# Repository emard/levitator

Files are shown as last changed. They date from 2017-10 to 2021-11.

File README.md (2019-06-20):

# Magnetic Levitation Toy

Object that horizonally levitates, artwork inspired
by flying a rocket to the Moon and back.

Magnets counter the gravity and provide forward
horizontal force (thrust) that is compensated
with a thread (rocket is anchored to the Moon).

3D printable parts, M3 threaded stainless steel rod
and 6 round (cylinder) neodymium magnets (0.5 T, grade N35).

    D =  6 mm, L = 10 mm, rod 14 mm
    D = 10 mm, L = 10 mm, rod 25 mm
    D = 12 mm, L = 12 mm, rod 25 mm

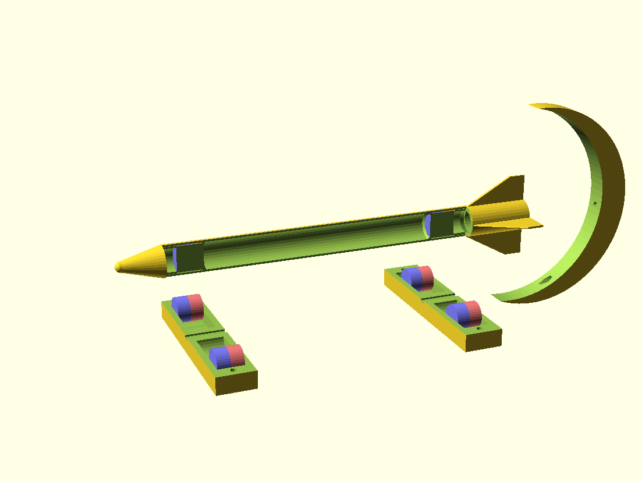
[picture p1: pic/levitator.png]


Range of mechanical stability is very narrow.
Millimeter precison adjustment is required to make
it right.

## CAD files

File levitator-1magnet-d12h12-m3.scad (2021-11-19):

include <levitator.scad>

/*
slicer-prusa

Print Settings:
layer height: 0.3 mm

Vertical sheels:
Perimeters: 2
Spiral vase: [ ]

Horizontal shells:
Solid layers: top: 2  bottom: 2

Infill: 10%

Output options:
Sequential individual objects [x]
Extruder clearance: Radius: 40 mm  Height: 40 mm

Advanced:
Seam: Nearest
[ ] External perimeters first

Printer Settings:
Extruder:
Retraction:
Length: 2.5 mm
Lift Z: 0.1 mm

Advanced
Use relative E distances: [ ]
Use firmware retraction:  [ ]
Use volumetric E:         [ ]
Enable variable layer
height feature:           [x]
*/

magnet_h=12;
magnet_d=12;

screw=3; // M3 screw
use_screws=0; // 0-disable screws, 1-enable screws
screw_plastic=2.2; // plastic hole dia
screw_plastic_tight=screw_plastic*0.82; // tight
// echo(screw_plastic_tight);
screw_plastic_loose=screw_plastic*1.1;
screw_plastic_head=screw_plastic*2.2;
screw_plastic_transition=1.5; // cone for easier printing
screw_plastic_under=3; // not counting transition

clr_magnet_d=0.5; // diameter clearance
clr_magnet_h=0.4; // length clearance
clr_screw_hole=0.25; // hole bit bigger
clr_screw_step=1; // screw spacing clearance

tube_wall=1.5; // wall thickness
tube_len=120; // tube length

screw_step=magnet_h+screw+clr_screw_step;
// screw_step=2*screw;

cylinder_faces=32; // smoothness

holder_depth=15;
// holder_width=72; // should be calculated from magnet_last and screw size
holder_height=15;
holder_thinner=0.35; // factor that makes middle bar thinner
holder_clr_magnet_d=clr_magnet_d;
holder_clr_magnet_h=clr_magnet_h;
magnet_first=[23,22]; // head,tail (22-23)
magnet_last=magnet_first; // head,tail
magnet_n=[1,1]; // tail,head
// magnet_step=5; // obsolete
magnet_height=holder_height/2;
holder_clearance=use_screws > 0.5 ? 0.3 : 0;

// stand

stand_d=10; // at threaded rod
stand_length=70;
stand_width=8;
stand_thickness=5;
stand_foot_length=70;
stand_foot_d=stand_width; // at floor

// head

head_len=18;
inlet_h=5;
head_inlet_clr=0.14; // head inlet clearance
head_transition=0.5; // easier printing
tiph=-2; // from tip to cutoff inside cone
head_tip=4; // tip diameter
head_tube_len=0; // head extension (like body)

// tail

tail_inlet_clr=0.13; // inlet clearance
wings=4;
wing_h1=10; // straignt height of the wing
wing_h2=40; // total wing height
wing_width=10;
wing_thick=tube_wall/2; // thickness
tail_transition=2;
holder_bar_h=4;

// stopper
stop_d=magnet_d-2*clr_magnet_d; // small d
stop_h=1.5;

levitation_h=37;

// moon artwork
moon_d1=levitation_h*2;
moon_d2=levitation_h*2;
moon_crescent=10;
moon_thick=8;
moon_angle=9;
moon_clr_screw_hole=0.2; // must be tight enough

// Rocket (spiral vase)
if(0)
  head();
if(0)
  tail();
if(0)
  rocket_tube();
// Stator (normal slicing)
if(0)
  printable_holders();
if(0)
  stand();
if(0)
  moon();

// cross section
if(1)
    // translate([0,0,55])
difference()
{
    // magnet_holder();
    // head();
    // tail();
    full_assembly(magnets=1);
    if(1)
    translate([magnet_d,0,0])
    cube([magnet_d*2,tube_len,magnet_d*2],center=true);
}

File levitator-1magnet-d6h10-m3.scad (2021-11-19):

include <levitator.scad>

/*
slicer-prusa

Print Settings:
layer height: 0.3 mm

Vertical sheels:
Perimeters: 1
Spiral vase: [ ]

Horizontal shells:
Solid layers: top: 1  bottom: 1

Infill: 10%

Output options:
Sequential individual objects [x]
Extruder clearance: Radius: 40 mm  Height: 40 mm

Advanced:
Seam: Nearest
[ ] External perimeters first

Printer Settings:
Extruder:
Retraction:
Length: 2.5 mm
Lift Z: 0.1 mm

Advanced
Use relative E distances: [ ]
Use firmware retraction:  [ ]
Use volumetric E:         [ ]
Enable variable layer
height feature:           [x]
*/

magnet_h=10;
magnet_d=6;

screw=3; // M3 screw
use_screws=0; // in plastic holders
screw_plastic=2.2; // plastic hole dia
screw_plastic_tight=screw_plastic*0.82; // tight
// echo(screw_plastic_tight);
screw_plastic_loose=screw_plastic*1.1;
screw_plastic_head=screw_plastic*2.2;
screw_plastic_transition=1.5; // cone for easier printing
screw_plastic_under=3; // not counting transition

clr_magnet_d=0.3; // diameter clearance (except holder)
clr_magnet_h=0.5; // length clearance (except holder)
clr_screw_hole=0.4; // hole bit bigger (except moon clr, defined on other place)
clr_screw_step=1; // screw spacing clearance

tube_wall=1.5; // wall thickness
tube_len=73; // tube length


screw_step=magnet_h+screw+clr_screw_step;

// screw_step=2*screw;

cylinder_faces=32;

holder_depth=15;
// holder_width=60; // obsolete, calculated from magnet_last and screw size
holder_height=8;
holder_thinner=0.5; // factor to make holder bars thinner
holder_clr_magnet_d=clr_magnet_d+0.2;
holder_clr_magnet_h=clr_magnet_h;
magnet_first=[14,13]; // head,tail
magnet_last=magnet_first;
magnet_n=[1,1]; // head,tail
magnet_height=holder_height/2; // in the middle of the holder
holder_clearance=use_screws > 0.5 ? 0.3 : 0;

// stand
stand_d=7; // at threaded rod
stand_length=50;
stand_width=6;
stand_thickness=5;
stand_foot_length=50;
stand_foot_d=6; // at floor

// head
head_len=12;
inlet_h=4;
head_inlet_clr=0.20; // head inlet clearance (positve=loose, negative=tight)
head_transition=0.5; // easier printing
tiph=-2; // from tip to cutoff inside cone
head_tip=3; // tip diameter
head_tube_len=0; // head extension (like body)

// tail
tail_inlet_clr=0.15; // tail inlet clearance (positive=loose, negative=tight)
wings=4;
wing_h1=5; // straignt height of the wing
wing_h2=25; // total wing height
wing_width=6;
wing_thick=tube_wall/2; // thickness
tail_transition=2;
holder_bar_h=4;

// stopper
stop_d=magnet_d-2*clr_magnet_d; // small d
stop_h=1.5;

levitation_h=21;

// moon artwork
moon_d1=2*levitation_h;
moon_d2=moon_d1;
moon_crescent=5; // width of crescent moon
moon_thick=7; // extrusion thickness
moon_angle=12;
moon_clr_screw_hole=0.15; // more tight, moon should not move

// ROCKET
if(0) // spiral vase seam rear
  head();
if(0) // spiral vase seam rear
  tail();
if(0) // spiral vase seam rear
  rocket_tube();
// STATOR
if(0) // print with seam: random for each piece be equal (no seam)
  printable_holders();
if(0)
  stand();
if(0)
  moon();

// cross section
if(1)
    // translate([0,0,55])
difference()
{
    // magnet_holder();
    // head();
    // tail();
    full_assembly(magnets=1);
    if(1)
    translate([magnet_d,0,0])
    cube([magnet_d*2,tube_len,magnet_d*2],center=true);
}

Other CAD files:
levitator-d10h10-m3.scad
levitator-d12h12-m3.scad
levitator-d6h10-m3.scad
levitator-insert-d6h10-m3.scad
levitator.scad
levitator/levitator.scad

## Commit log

2017-09-19 initial parts, 3D printable parts for the levitator
    [levitator.scad]
2017-09-20 closed magnet holder wip
    [levitator.scad]
2017-09-20 plastic screw head on the side
    [levitator.scad]
2017-09-20 magnet holder works. When 2 magnets are placed at most distant position, stable lifting field appears
    [levitator.scad]
2017-09-20 deleting out-of-directory file
    [levitator.scad]
2017-09-20 moving files around
    [levitator.scad]
2017-09-20 enable both halves
    [levitator.scad]
2017-09-22 levitator head done, fits tight into tube
    [levitator.scad]
2017-09-22 tail WIP
    [levitator.scad]
2017-09-22 tail inlet
    [levitator.scad]
2017-09-22 levitator - full assembly
    [levitator.scad]
2017-09-22 full assembly with holders
    [levitator.scad]
2017-09-23 dimensions adjusted
    [levitator.scad]
2017-09-23 full view
    [levitator.scad]
2017-09-23 moon angle changed
    [levitator.scad]
2017-09-23 proper orientation (rocket horizontal)
    [levitator.scad]
2017-09-23 reduce clearances on M3 rod and tail - more tight
    [levitator.scad]
2017-09-26 magnets shown in proper positions
    [levitator.scad]
2017-09-29 wing enclosing cone calculated
    [levitator.scad]
2017-09-29 various number of wings now works 3-n
    [levitator.scad]
2017-09-29 make it work for 2 wings also
    [levitator.scad]
2017-09-30 magnet_holder: set default argument magnet=0
    [levitator.scad]
2017-10-22 Separating library from geometry and making versions for magneds D=6 H=10 and D=10 H=10 mm
    [levitator-d10h10-m3.scad, levitator-d6h10-m3.scad, levitator.scad]
2017-10-24 cosmetics and D=6 dimensions adjustment, tightening head/tail inlet clearances
    [levitator-d10h10-m3.scad, levitator-d6h10-m3.scad, levitator.scad]
2017-10-24 dimensions adjustment
    [levitator-d6h10-m3.scad]
2017-10-25 smaller holders
    [levitator-d6h10-m3.scad]
2017-10-25 thinner moon
    [levitator-d6h10-m3.scad]
2017-10-25 update levitation height
    [levitator-d6h10-m3.scad]
2017-10-27 more configurable positions of magnets in the holders
    [levitator-d10h10-m3.scad, levitator-d6h10-m3.scad, levitator.scad]
2017-10-27 it works, maybe rocket is too steep upwards
    [levitator-d6h10-m3.scad]
2017-10-28 D=6 L=10 mm: adjusting dimensions so that rocket levitates mostly horizontal, with a slight up-slope. Thickening moon.
    [levitator-d6h10-m3.scad]
2017-10-28 D=6 L=10 larger tail (cosmetics)
    [levitator-d6h10-m3.scad]
2017-10-28 shorten tube 7->6cm, cosmetics
    [levitator-d6h10-m3.scad]
2017-10-28 simplifying design: holders without screws
    [levitator-d10h10-m3.scad, levitator-d6h10-m3.scad, levitator.scad]
2017-10-28 no screws, no holder clearance
    [levitator-d10h10-m3.scad, levitator-d6h10-m3.scad]
2017-10-28 D=10 L=10: tail holder is shorter than head holder
    [levitator-d10h10-m3.scad]
2017-10-28 no screws case: holder middle half-height, material and print time saving
    [levitator.scad]
2017-10-29 holder inner round a bit smaller than outer rounds. print time saving
    [levitator.scad]
2017-11-11 allow holder bar be optinally thinner by a factor
    [levitator.scad]
2017-11-11 update dimensions for 6x10, 10x10 and new 12x12 magnets
    [levitator-d10h10-m3.scad, levitator-d12h12-m3.scad]
2018-07-03 d6m10: more tight head and tail inlets
    [levitator-d6h10-m3.scad]
2018-07-03 d12h12: dimensions adjusted
    [levitator-d12h12-m3.scad]
2018-08-18 printing rocket and holders as one piece, pausing printer to insert magnets
    [levitator.scad]
2018-08-18 d=6 h=10 paused print for magnets insertion
    [levitator-insert-d6h10-m3.scad]
2018-08-18 floor stand
    [levitator.scad]
2018-08-18 d=6 h=10 with floor stand
    [levitator-insert-d6h10-m3.scad]
2018-08-19 pause example
    [levitator-insert-d6h10-m3.scad]
2018-08-19 d=12 h=12 updated geometry
    [levitator-d12h12-m3.scad]
2018-08-19 pause better explained
    [levitator-insert-d6h10-m3.scad]
2018-08-24 adjusting dimensions for magnet insertion
    [levitator-insert-d6h10-m3.scad]
2018-08-24 adjusting dimensions
    [levitator-d6h10-m3.scad]
2019-06-11 d6h10 update for standing at angle
    [levitator-d6h10-m3.scad]
2019-06-11 d6h10 reduce height
    [levitator-d6h10-m3.scad]
2019-06-11 d6h10: adjusting dimensions
    [levitator-d6h10-m3.scad]
2019-06-12 d12h12: adujusting dimensions
    [levitator-d12h12-m3.scad]
2019-06-17 moon screw hole clearance set separately to make it tight enough
    [levitator-d10h10-m3.scad, levitator-d12h12-m3.scad, levitator-d6h10-m3.scad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]
2019-06-17 d12h12: shorten tube 120->100 mm in order to move center of mass down. When using 250 mm threaded rod 120 mm tube was not stable if mounted at angle on a stand.
    [levitator-d12h12-m3.scad]
2019-06-18 trying to use "Seam: Nearest" (but seam looks the same)
    [levitator-d6h10-m3.scad]
2019-06-20 correctly placed magnets on full_assembly
    [levitator.scad]
2019-06-20 d12h12: tighten inlet clearance
    [levitator-d12h12-m3.scad, levitator-d6h10-m3.scad]
2019-06-20 top and bottom layers: same number of shells
    [levitator-d12h12-m3.scad, levitator-d6h10-m3.scad]
2020-12-15 head tube len parameter
    [levitator-d10h10-m3.scad, levitator-d12h12-m3.scad, levitator-d6h10-m3.scad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]
2020-12-26 support 1 and 2 magnets
    [levitator.scad]
2020-12-26 1-magnet update
    [levitator-1magnet-d6h10-m3.scad]
2020-12-26 increase clearances in magnet holder for mangets and rod
    [levitator-1magnet-d6h10-m3.scad]
2020-12-27 separate magnet clearance from holder
    [levitator.scad]
2020-12-27 followup common change in levitator.scad for separate magnet clr in holder
    [levitator-1magnet-d6h10-m3.scad, levitator-d10h10-m3.scad, levitator-d12h12-m3.scad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]
2021-11-16 shorten tube len 75->73 mm, inclination more upwards
    [levitator-1magnet-d6h10-m3.scad]
2021-11-19 1-magnet d6h10 comments update
    [levitator-1magnet-d6h10-m3.scad]
2021-11-19 1-magnet d12h12
    [levitator-1magnet-d12h12-m3.scad]
